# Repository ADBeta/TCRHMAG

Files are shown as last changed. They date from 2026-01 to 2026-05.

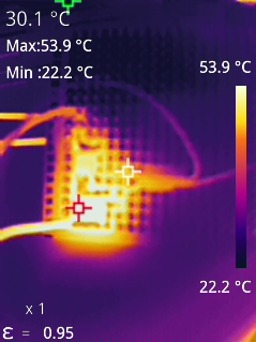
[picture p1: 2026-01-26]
Images/TestBoard_Thermals_100%PWM.jpg

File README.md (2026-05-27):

# Temperature Controlled Ryobi Hot Melt Adhesive Gun

An Upgrade Control Board for the R18GLU Hot Glue Gun to provide PID Temperature
Control, and display battery voltage, battery current.  
It also improves battery life to 1hr 45min on a 1.5Ah Ryobi Battery (At 150c).

## Features
This is a drop-in replacement Controller PCB, which provides:

* OLED Display which shows
    * Target and Actual Temperature
    * Battery Current draw
    * Battery Voltage (and Battery Bar)
* Overcurrent and Undervoltage Protection
* Adjustable PID Control loop
* LED Status Light
* Precise Temperature Control (+/-5 degrees celcius)

## How do I install this mod?
This upgrade will require ordering PCBs & components, soldering, modifying the
chassis, and barrel of the Glue Gun as well as 3D Printing.  
TCRHMAG is a medium difficulty hobby project.

1) Remove the Original Controller board and remove the wires from the Power Switch
2) **MODIFICATION STEPS**  
2a) Drill a small hole in the Glue Gun's heater barrel for better thermal control,
and use a thermally rated (280c) adhesive to attach an NTC Thermistor (TODO: images and specs of thermistor)
2b) Create a notch in both halves of the Glue Gun Shell for the OLED and Control wires (TODO: Images)
using a Dremel or sharp knife etc.
2c) (TODO: add display control 3d printed housing)
3) Install the programmed PCB
4) Solder the Power Switch to the PCB, and solder the Thermistor, Heater, LED
and Battery cables to the PCB
5) **3D PRINTED OLED HOUSING STEPS**
5a)......

## Programming The Microcontorller
**IMPORTANT** Solder and Flash the MCU **BEFORE** Assembling the rest of the PCB  
The NRST Line is used by an OpAmp circuit so it CANNOT be flashed in-situ until
the NRST line is disabled by the first Flash Cycle.
After this initial Programming Step, the board can be fully assembled and 
re-programmed if necessary without removing parts.

Use [minichlink](https://github.com/cnlohr/ch32fun/tree/master/minichlink) to
program the MCU.  
This project is built using [ch32fun](https://github.com/cnlohr/ch32fun).

## Bill of Materials

## To Do
* Display in Faranheit?
* Add better Rotary Encoder filter circuit
* Fix noisy battery voltage sensing
* Larget OLED / Rotary Encoder solder pads

----
Copyright (c) 2026 ADBeta

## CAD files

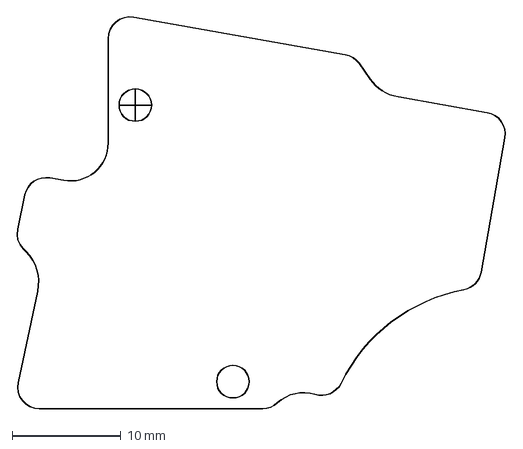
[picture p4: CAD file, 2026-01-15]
PCB/TCRHMAG-PCB-MkIII.dxf
45.2 x 36.2 mm

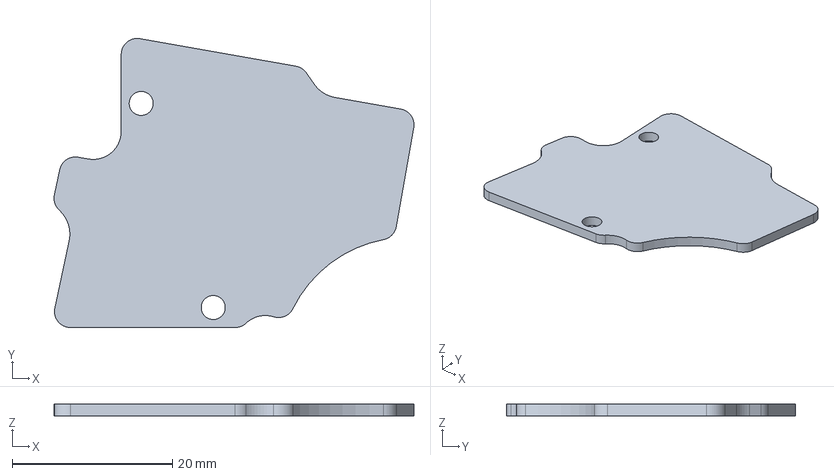
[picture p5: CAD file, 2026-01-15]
PCB/TCRHMAG.FCStd
45.0 x 36.1 x 1.50 mm

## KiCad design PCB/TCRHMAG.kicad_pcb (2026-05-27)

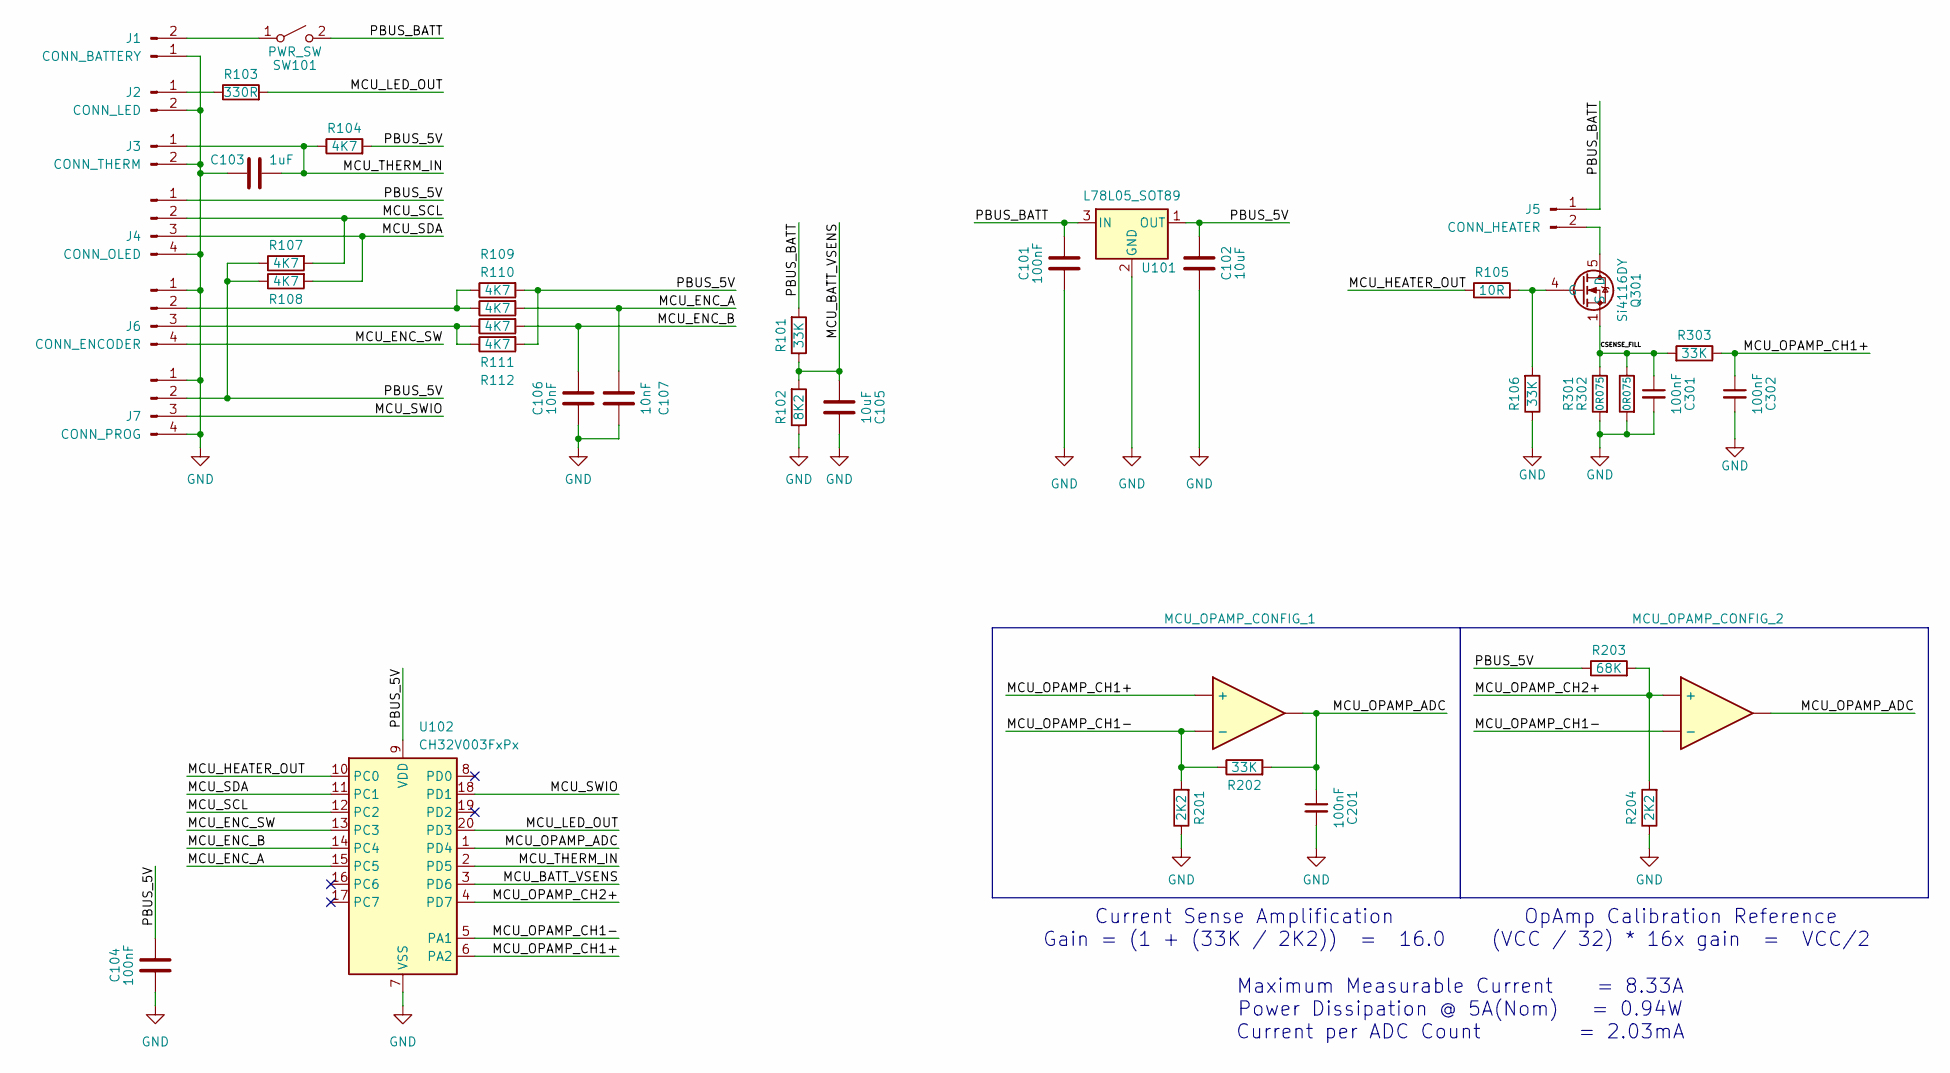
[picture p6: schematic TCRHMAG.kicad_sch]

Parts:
C101, C104, C201, C301, C302: 100nF; C_0402_1005Metric
C102, C105: 10uF; C_0402_1005Metric
C103: 1uF; C_0402_1005Metric
C106, C107: 10nF; C_0402_1005Metric
J1: CONN_BATTERY; Power_Conn
J2: CONN_LED; Signal_Conn
J3: CONN_THERM; Signal_Conn
J4: CONN_OLED; PinSocket_1x04_P2.00mm_Vertical
J5: CONN_HEATER; Power_Conn
J6: CONN_ENCODER; PinSocket_1x04_P2.00mm_Vertical
J7: CONN_PROG; Program_Conn
MCU_OPAMP_CONFIG_1, MCU_OPAMP_CONFIG_2: (no value)
Q301: Si4116DY; SOIC-8_3.9x4.9mm_P1.27mm
R101, R106, R202, R303: 33K; R_0402_1005Metric
R102: 8K2; R_0402_1005Metric
R103: 330R; R_0402_1005Metric
R104, R107, R108, R109, R110, R111, R112: 4K7; R_0402_1005Metric
R105: 10R; R_0402_1005Metric
R201, R204: 2K2; R_0402_1005Metric
R203: 68K; R_0402_1005Metric
R301, R302: 0R075; R_2512_6332Metric_Pad1.40x3.35mm_HandSolder
SW101: PWR_SW; U13SS_Switch
U101: L78L05_SOT89; SOT-89-3
U102: CH32V003FxPx; TSSOP-20_4.4x6.5mm_P0.65mm

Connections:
/CSENSE_FILL: C301.1, Q301.1 (S), Q301.2 (S), Q301.3 (S), R301.1, R302.1, R303.2
/MCU_BATT_VSENS: C105.1, R101.1, R102.2, U102.3 (PD6)
/MCU_ENC_A: C107.2, R110.2, U102.15 (PC5)
/MCU_ENC_B: C106.2, R111.2, U102.14 (PC4)
/MCU_ENC_SW: J6.4, U102.13 (PC3)
/MCU_HEATER_OUT: R105.1, U102.10 (PC0)
/MCU_LED_OUT: R103.2, U102.20 (PD3)
/MCU_OPAMP_ADC: C201.1, MCU_OPAMP_CONFIG_1.3, MCU_OPAMP_CONFIG_2.3, R202.2, U102.1 (PD4)
/MCU_OPAMP_CH1+: C302.1, MCU_OPAMP_CONFIG_1.1 (+), R303.1, U102.6 (PA2)
/MCU_OPAMP_CH1-: MCU_OPAMP_CONFIG_1.2 (-), MCU_OPAMP_CONFIG_2.2 (-), R201.2, R202.1, U102.5 (PA1)
/MCU_OPAMP_CH2+: MCU_OPAMP_CONFIG_2.1 (+), R203.2, R204.2, U102.4 (PD7)
/MCU_SCL: J4.2, R107.2, U102.12 (PC2)
/MCU_SDA: J4.3, R108.2, U102.11 (PC1)
/MCU_SWIO: J7.3, U102.18 (PD1)
/MCU_THERM_IN: C103.2, J3.1, R104.1, U102.2 (PD5)
/PBUS_5V: C102.1, C104.1, J4.1, J7.2, R104.2, R107.1, R108.1, R109.2, R112.2, R203.1, U101.1 (OUT), U102.9 (VDD)
/PBUS_BATT: C101.1, J5.1, R101.2, SW101.2 (B), U101.3 (IN)
GND: C101.2, C102.2, C103.1, C104.2, C105.2, C106.1, C107.1, C201.2, C301.2, C302.2, J1.1, J2.2, J3.2, J4.4, J6.1, J7.1, J7.4, R102.1, R106.1, R201.1, R204.1, R301.2, R302.2, U101.2 (GND), U102.7 (VSS)
unnamed: J1.2, SW101.1 (A)
unnamed: J2.1, R103.1
unnamed: J5.2, Q301.5 (D), Q301.6 (D), Q301.7 (D), Q301.8 (D)
unnamed: J6.2, R109.1, R110.1
unnamed: J6.3, R111.1, R112.1
unnamed: Q301.4 (G), R105.2, R106.2

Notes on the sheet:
OpAmp Calibration Reference (VCC / 32) * 16x gain = VCC/2
Current Sense Amplification Gain = (1 + (33K / 2K2)) = 16.0
Maximum Measurable Current = 8.33A Power Dissipation @ 5A(Nom) = 0.94W Current per ADC Count = 2.03mA

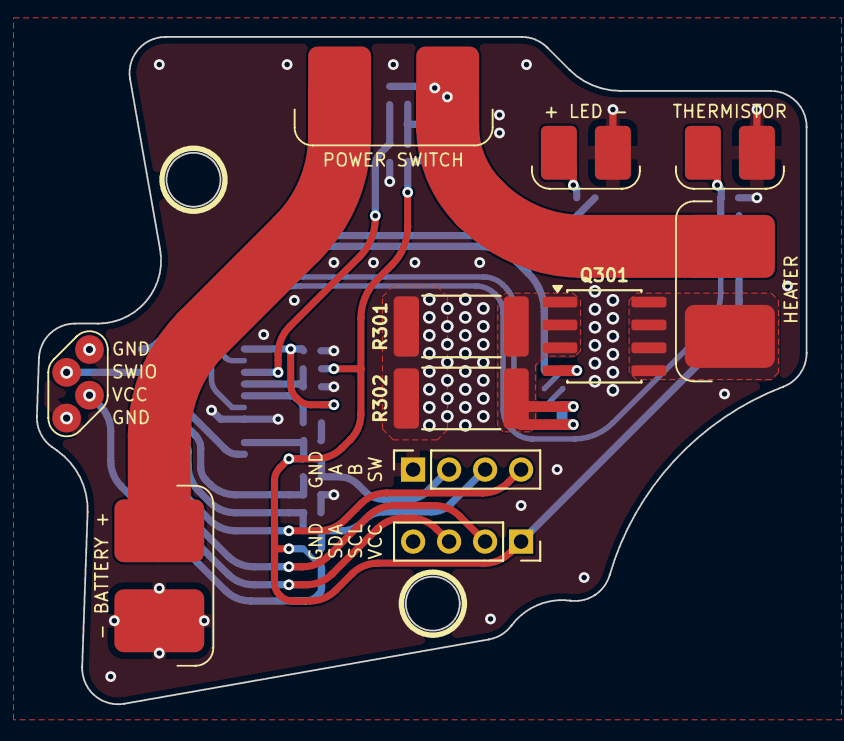
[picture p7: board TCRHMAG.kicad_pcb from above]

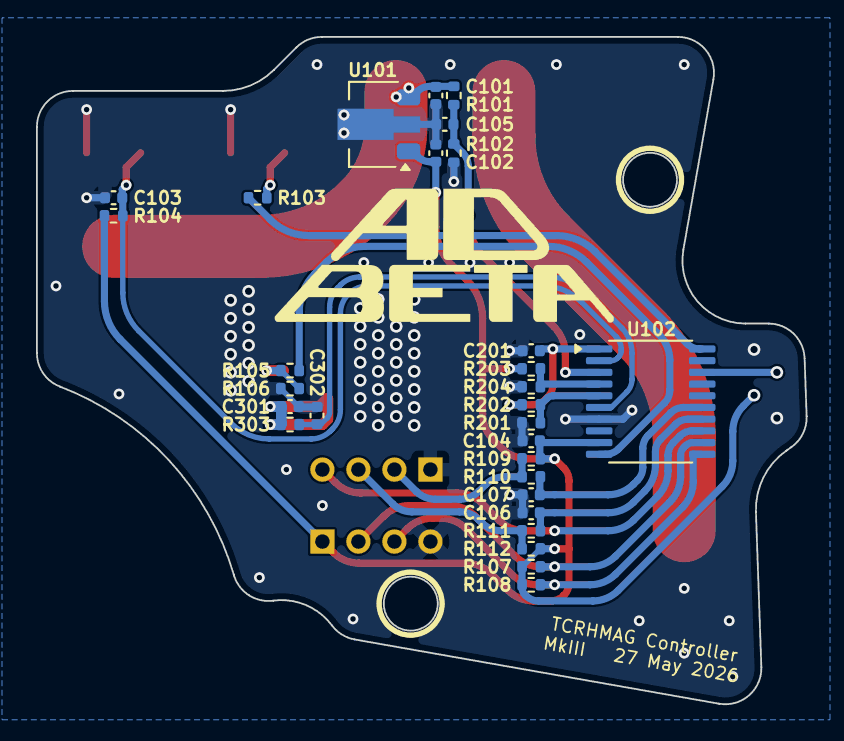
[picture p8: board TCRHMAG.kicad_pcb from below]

Board: 2 copper layers, 42.8 x 37.1 mm, 40 parts (29 on the bottom side), 24 nets.

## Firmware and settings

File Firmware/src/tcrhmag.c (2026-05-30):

/******************************************************************************
* PID Thermally Controlled Ryobi Hot Melt Adhesive Gun (HMAG)
* Uses OLED Display to show the Battery and Temperature Status, with
* Rotary Encoder for UI Inputs 
* See the GitHub for full documentation: https://github.com/ADBeta/TCRHMAG
*
*
* ---- Pinout ----
* PA1    OPAMP_CH1-
* PA2    OPAMP_CH1+
*
* PC0    PWM Out           (TIM2 CH3)
* PC1    I2C SDA
* PC2    I2C_SCL
* PC3    Rotary Encoder Switch
* PC4    Rotary Encoder A
* PC5    Rotary Encoder B
*
* PD3    LED Out           (TIM2 CH2)
* PD4    OPAMP_ADC         (ADC7)
* PD5    Thermistor ADC    (ADC5)
* PD6    Battery Sense     (ADC6)
* PD7    OPAMP_CH2+
*
* ---- TODO ----
* - Scheduler Library
* - Add UI for PID adjust
* - Store the previous Target temp in flash
*
* Ver 1.8     30 May 2026
* (c) ADBeta 2026
******************************************************************************/
#include <ch32fun.h>
#include "thermistor_lut.h"
#include "sysinit.h"
#include "battery.h"
#include "oled.h"

#include "lib_scheduler.h"
#include "lib_gpioctrl.h"
#include "lib_i2c.h"
#include "lib_pid.h"

#include <stdio.h>
#include <stdbool.h>



/*** Macro Functons **********************************************************/
#define CLAMP(x, min, max) ((x) < (min) ? (min) : ((x) > (max) ? (max) : (x)))



/*** Pin Definitions *********************************************************/
#define OPAMP_CHA1_NEG                GPIO_PA1
#define OPAMP_CHA1_POS                GPIO_PA2
#define OPAMP_CHA2_POS                GPIO_PD7
#define PWM_OUT                       GPIO_PC0

#define ROTENC_SW_PIN                 GPIO_PC3
#define ROTENC_A_PIN                  GPIO_PC4
#define ROTENC_B_PIN                  GPIO_PC5

#define THERM_ADC_PIN                 GPIO_A5
#define THERM_ADC_CH                  GPIO_ADC_A5
#define BSENS_ADC_PIN                 GPIO_A6
//#define BSENS_ADC_CH                GPIO_ADC_A6
#define OPAMP_ADC_PIN                 GPIO_A7
//#define OPAMP_ADC_CH                GPIO_ADC_A7

#define PWM_CHANNEL_LED               0
#define PWM_CHANNEL_HEATER            1



/*** Timing Values ***********************************************************/
#define MILLIS_LED_UPDATE            25
#define MILLIS_USER_INPUT_UPDATE     50
#define MILLIS_PID_HEATER_UPDATE     100
#define MILLIS_BATTERY_CHECK         250
#define MILLIS_DISPLAY_UPDATE        125



/*** Misc Definitions ********************************************************/
#define LED_OFF_PWM                  0
#define LED_MINIMUM_PWM              30
#define LED_MAXIMUM_PWM              255
#define LED_FLASH_TICKS              10


/*** Typedefs and Structures *************************************************/
typedef enum {
	SYSTEM_STATE_BOOT                      = 0,
	SYSTEM_STATE_HEATER_DISABLED,
	SYSTEM_STATE_HEATER_ENABLED,
	SYSTEM_STATE_ERROR_UNDERVOLTAGE,
	SYSTEM_STATE_ERROR_OVERCURRENT,
} system_state_e;

	
typedef enum {
	UI_MODE_UNSET                          = 0,
	UI_MODE_CHANGE_TEMP,
	UI_MODE_CHANGE_KP,
	UI_MODE_CHANGE_KI,
	UI_MODE_CHANGE_KD,
	UI_MODE_ERROR_UNDERVOLTAGE,
	UI_MODE_ERROR_OVERCURRENT,
} user_input_mode_e;



/*** Global Variables ********************************************************/
// External 1ms SysTick counter variable
volatile uint32_t _systick_millis                                = 0;


/// System Status and Settings ////////////////////////////////////////////////
// System //////
static system_state_e      g_system_state                        = SYSTEM_STATE_BOOT;
static user_input_mode_e   g_user_input_mode                     = UI_MODE_CHANGE_TEMP;
static volatile int16_t    g_rotary_encoder_clicks               = 0;
// Battery /////
static uint16_t            g_battery_voltage_mv                  = 0;
static uint16_t            g_battery_current_ma                  = 0;
static uint8_t             g_battery_percentage                  = 0;
// Heater //////
#define                    SETTING_TEMPERATURE_MINIMUM           50
#define                    SETTING_TEMPERATURE_MAXIMUM           220
#define                    SETTING_TEMPERATURE_INCRIMENT         5
static int16_t             g_target_temperature                  = SETTING_TEMPERATURE_MINIMUM;
static int16_t             g_actual_temperature                  = 0;

/// @brief Gray Code Lookup Table for the Rotary Encoder
static const int8_t rotenc_table[16] = 
{
	 0,  -1,   1,   0,
	 1,   0,   0,  -1,
	-1,   0,   0,   1,
	 0,   1,  -1,   0
};

/// @brief Base Settings for the PID Controller for the Heater
static pid_ctrl_t heater_pid =
{
	.Kp        = 1000,
	.Ki        = 5,
	.Kd        = 5,
	.scale     = 100,

	.out_min   = 0,
	.out_max   = 255
};

/// @brief I2C Device for the OLED
static i2c_device_t i2c_oled = 
{
	.clkr = I2C_CLK_1MHZ,
	.type = I2C_ADDR_7BIT,
	.addr = 0x3C,
	.regb = 1,
	.tout = 2000,
};



/*** Scheduler Task Functions ************************************************/
/// @brief Updates the Status LED
static void led_update_task(void);

/// @brief Gets User Input Values
static void user_input_task(void);

/// @biref Update PID Controller for the heater
static void pid_heater_task(void);

/// @brief Check the battery Voltage/Current
static void battery_check_task(void);

/// @brief Update the display
static void display_update_task(void);



/*** Function Declarations ***************************************************/
/// @brief Initialises the EXTI7_0 Rotary Encoder IRQ
/// @param None
/// @return None
static void EXTI7_0_Init(void);


/// @brief EXTI Pin Change Interrupt - Handles the Rotary Encoder stepping
/// @param None
/// @return None
__attribute__((interrupt)) 
void EXTI7_0_IRQHandler(void);


/// @breif Sets the Duty Cycle of the given PWM Channel. Max input is 255
/// @param ch, channel to change (Only 2 & 3 are valid)
/// @param duty, input duty cycle value
/// @return none
static void pwm_set_duty(const uint8_t ch, const uint32_t duty);


/// @brief Converts a given Thermistor Raw ADC Value to a Temperature (c)
/// using Linear Interpolation of the Pre-computed LUT
/// @param adc, Raw ADC Value of the Thermistor
/// @return Temperature in degrees Celcius
static uint16_t thermistor_adc_to_temp(const uint16_t adc);



/*** Main ********************************************************************/
int main(void)
{
	SystemInit();

	// I2C Setup for the OLED
	i2c_init(&i2c_oled);

	// Initialise the OLED, then display the BOOTING Screen
	Delay_Ms(20);
	oled_init(&i2c_oled);
	oled_draw_boot_screen();
	oled_update();

	// Initialise PWM Channels. Turn off the Heater (CH3) and the LED on (CH2)
	pwm_init();
	pwm_set_duty(PWM_CHANNEL_LED,    0x00);
	pwm_set_duty(PWM_CHANNEL_HEATER, 0x00);
	
	// Set the Rotary Encoder Pins to INPUT_PULLUP
	gpio_set_mode(ROTENC_SW_PIN, INPUT_PULLUP);
	gpio_set_mode(ROTENC_A_PIN,  INPUT_PULLUP);
	gpio_set_mode(ROTENC_B_PIN,  INPUT_PULLUP);

	// Initiliase the ADC to use 24MHz clock, and Sample for 43 Clock Cycles
	gpio_init_adc(ADC_CLOCK_DIV_2, ADC_SAMPLE_CYCLES_43);

	// Initialise the OpAmp Pins - Use CHA1 +/-,  CHA2 +, and ADC Output
	gpio_set_mode(OPAMP_CHA1_NEG, INPUT_FLOATING);
	gpio_set_mode(OPAMP_CHA1_POS, INPUT_FLOATING);
	gpio_set_mode(OPAMP_CHA2_POS, INPUT_FLOATING);

	gpio_set_mode(THERM_ADC_PIN,  INPUT_ANALOG);
	gpio_set_mode(BSENS_ADC_PIN,  INPUT_ANALOG);
	gpio_set_mode(OPAMP_ADC_PIN,  INPUT_ANALOG);	

	gpio_init_opamp();
	gpio_set_opamp_inputs(GPIO_OPAMP_CH1_POS, GPIO_OPAMP_CH1_NEG);
	opamp_calibrate();

	// Initialise the Rotary Encoder IRQ
	EXTI7_0_Init();

	// Initialise the SysTick to get millis() funcitonality
	systick_init();

	// TODO:
	// Get user settings from flash
	pid_init(&heater_pid);

	// TODO: Change via UI
	g_system_state    = SYSTEM_STATE_HEATER_DISABLED;
	g_user_input_mode = UI_MODE_CHANGE_TEMP;
	

	// Add all the tasks to the scheduler
	scheduler_add(led_update_task,     MILLIS_LED_UPDATE);
	scheduler_add(user_input_task,     MILLIS_USER_INPUT_UPDATE);
	scheduler_add(pid_heater_task,     MILLIS_PID_HEATER_UPDATE);
	scheduler_add(battery_check_task,  MILLIS_BATTERY_CHECK);
	scheduler_add(display_update_task, MILLIS_DISPLAY_UPDATE);


	// Initialise the IWDT to prevent a lockup - 250ms
	iwdg_init(0x04, 0x9B);


	while(true)
	{
		// Run the Scheduler
		scheduler_run(_systick_millis);

		// Keep the Watchdog fed and happy :)
		iwdg_feed();
	}

	return 0;
}







/*** Scheduler Functions *****************************************************/
static void led_update_task(void)
{
	static int16_t led_val   = 0;
	static int8_t  led_inc   = 5;
	static uint8_t led_ticks = LED_FLASH_TICKS;
	
	switch(g_system_state)
	{
		case SYSTEM_STATE_HEATER_DISABLED:
			led_val = LED_MINIMUM_PWM;
			break;
	
		case SYSTEM_STATE_HEATER_ENABLED:
			led_val += led_inc;
			if(led_val >= LED_MAXIMUM_PWM || led_val <= LED_MINIMUM_PWM)
			{
				led_val = (led_val >= LED_MAXIMUM_PWM) ? LED_MAXIMUM_PWM : LED_MINIMUM_PWM;
				led_inc = -led_inc;
			}
			break;

		case SYSTEM_STATE_ERROR_OVERCURRENT:
		case SYSTEM_STATE_ERROR_UNDERVOLTAGE:
			if(--led_ticks == 0)
			{
				led_val = (led_val == LED_OFF_PWM) ? LED_MAXIMUM_PWM : LED_OFF_PWM;
				led_ticks = LED_FLASH_TICKS;
			}
			break;

		default:
			led_val = LED_OFF_PWM;
			break;
	}

	// Set the LED PWM
	pwm_set_duty(PWM_CHANNEL_LED, (uint8_t)led_val);
}


static void user_input_task(void)
{
	// Determine if the RENC button has been pressed
           GPIO_STATE curr = gpio_digital_read(ROTENC_SW_PIN);
	static GPIO_STATE prev = true;
	bool button_pressed = (prev && !curr);
	prev = curr;


	// If the system in is the error state, ignore all user inputs
	if(g_system_state == SYSTEM_STATE_ERROR_UNDERVOLTAGE || g_system_state == SYSTEM_STATE_ERROR_OVERCURRENT)
	{
		g_rotary_encoder_clicks = 0;
		return;
	}

	//TODO: Move UI stuff to helper function and .h for neatness
	switch(g_user_input_mode)
	{
		case UI_MODE_CHANGE_TEMP:
			// Incriment / Decriment the Target Temp by the current clicks
			// Limit to min and max values, then reset clicks
			g_target_temperature = CLAMP(g_target_temperature + g_rotary_encoder_clicks * SETTING_TEMPERATURE_INCRIMENT, 
								         SETTING_TEMPERATURE_MINIMUM, 
								         SETTING_TEMPERATURE_MAXIMUM);
			
			// Toggle ENABLE if button was pressed
			if(button_pressed)
			{
				// TODO: Neater
				if(g_system_state == SYSTEM_STATE_HEATER_DISABLED)
				{
					g_system_state = SYSTEM_STATE_HEATER_ENABLED;
				} else if(g_system_state == SYSTEM_STATE_HEATER_ENABLED) {
					g_system_state = SYSTEM_STATE_HEATER_DISABLED;
				}
			}
			break;

		default:
			break;
	}
	

	g_rotary_encoder_clicks = 0;
}


static void pid_heater_task(void)
{
	// Get the RAW ADC Value from the Thermistor, and convert it to an
	// interpolated Temperature
	uint16_t thermistor_adc = gpio_analog_read(THERM_ADC_CH);
	g_actual_temperature = thermistor_adc_to_temp(thermistor_adc);
	
	// Calculate the PWM Value needed for the heater using PID - regardless
	// of enabled state to keep the PID loop up-to-date
	int32_t heater_pwm = pid_calculate(&heater_pid, g_actual_temperature, g_target_temperature);
	
	// If the heater is disabled, set PWM value to 0 (OFF)
	if(g_system_state != SYSTEM_STATE_HEATER_ENABLED) 
		heater_pwm = 0x00;
	
	pwm_set_duty(PWM_CHANNEL_HEATER, (uint8_t)heater_pwm);
}


static void battery_check_task(void)
{
	uint16_t system_mv = gpio_read_system_mv();

	g_battery_voltage_mv = battery_read_mv(system_mv);
	g_battery_percentage = battery_calc_battery_percent(g_battery_voltage_mv);
	g_battery_current_ma = battery_read_average_ma(system_mv);

	// If the battery voltage drops below the minimum, or the current
	// goes above maximum, put the glue gun into a lockout state to
	// failsafe. Also starts to cooldown
	static uint8_t error_ticks = 10;
	bool voltage_fault = (g_battery_voltage_mv <= BATTERY_EMPTY_MV); 
	bool current_fault = (g_battery_current_ma >= BATTERY_OVERCURRENT_MA);
	
	if(!voltage_fault && !current_fault)
		error_ticks = 10;

	if(--error_ticks == 0)
	{
		g_system_state = voltage_fault ? SYSTEM_STATE_ERROR_UNDERVOLTAGE :
		                                 SYSTEM_STATE_ERROR_OVERCURRENT;
		
		g_user_input_mode = voltage_fault ? UI_MODE_ERROR_UNDERVOLTAGE :
			                                UI_MODE_ERROR_OVERCURRENT;
	}
}


static void display_update_task(void)
{
	static user_input_mode_e p_user_input_mode = UI_MODE_UNSET;
	if(p_user_input_mode != g_user_input_mode)
	{
		oled_clear_display();
		p_user_input_mode = g_user_input_mode;
	}

	switch(g_user_input_mode)
	{
		case UI_MODE_CHANGE_TEMP:
			oled_draw_battery_current(g_battery_current_ma);
//			oled_draw_battery_voltage(g_battery_voltage_mv);
			oled_draw_battery_percent(g_battery_percentage);
			oled_draw_temperature(g_target_temperature, g_actual_temperature);
			oled_draw_heater_state(g_system_state == SYSTEM_STATE_HEATER_ENABLED);
			break;

		case UI_MODE_ERROR_UNDERVOLTAGE:
			oled_draw_error_undervoltage_screen();
			break;

		case UI_MODE_ERROR_OVERCURRENT:
			oled_draw_error_overcurrent_screen();
			break;

		default:
			break;
	}

	oled_update();
}



/*** Function Definitions ****************************************************/
static void EXTI7_0_Init(void)
{
	// Enable AFIO and CH4 and CH5 on PORTC
	RCC->APB2PCENR |= RCC_APB2Periph_AFIO;
	AFIO->EXTICR    = AFIO_EXTICR_EXTI4_PC | AFIO_EXTICR_EXTI5_PC;
	
	// Enable IRQ on Channel 4 & 5, Rising or Falling Edge
	EXTI->INTENR    = EXTI_INTENR_MR4 | EXTI_INTENR_MR5;
	EXTI->RTENR     = EXTI_RTENR_TR4  | EXTI_RTENR_TR5;
	EXTI->FTENR     = EXTI_FTENR_TR4  | EXTI_FTENR_TR5;

	// Clear IRQ Flags before enabling for safety
	EXTI->INTFR = 0x00000030;
	// Enable the EXTI0-7 Interrupt Group in NVIC
	NVIC_EnableIRQ(EXTI7_0_IRQn);
}


__attribute__((interrupt))
void EXTI7_0_IRQHandler(void)
{
	// Trigger on CH4 and CH5
	if((EXTI->INTFR & 0x00000010) || (EXTI->INTFR & 0x00000020))
	{
		// Read the PORT Input Register to get the Pinm Bits
		uint32_t portc_read = GPIOC->INDR;

		// Clear whichever flag was hit
		if(EXTI->INTFR & 0x10) EXTI->INTFR = 0x10;
		if(EXTI->INTFR & 0x20) EXTI->INTFR = 0x20;

		// Accumulate transitions per detend (usually 4) 
		static int8_t accumulator     = 0;
		
		// Read A and B Pins (PC4 & PC5), use their state as bits in a bitmask. [AB]
		static int8_t rotenc_prev_bitmask = 0b11;
		       int8_t rotenc_curr_bitmask = (((portc_read >> 4) & 1) << 1) | ((portc_read >> 5) & 1);

		// Convert the bitmasks into a step value using the Gray Code Table
		int8_t step = rotenc_table[ (rotenc_prev_bitmask << 2) | rotenc_curr_bitmask ];
		accumulator += step;

		// If the Accumulator has incrimented or decrimented by the number of clicks
		// per indent (4), incriment or decriment the global value
		     if(accumulator >=  4) { g_rotary_encoder_clicks++; accumulator -= 4; }
		else if(accumulator <= -4) { g_rotary_encoder_clicks--; accumulator += 4; }
	
		// Update the prev bitmask for the next interrupt
		rotenc_prev_bitmask = rotenc_curr_bitmask;
	}
}


static  void pwm_set_duty(const uint8_t ch, const uint32_t duty)
{
	static volatile uint32_t *tim_ptr[2] = { &TIM2->CH2CVR, &TIM2->CH3CVR };
	*tim_ptr[ch] = duty;
}


static uint16_t thermistor_adc_to_temp(const uint16_t adc)
{
	const size_t therm_max_index = THERMISTOR_PAIR_ENTRIES - 1;
	
	// Cap the Upper and Lower Bounds
	if(adc >= thermistor_pair[0].adc)
		return thermistor_pair[0].temp_c;
	
	if(adc <= thermistor_pair[therm_max_index].adc)
		return thermistor_pair[therm_max_index].temp_c;


	// Find the LUT ADC Range
	for(size_t ti = 0; ti < therm_max_index; ti++)
	{
		// Get the Current and Next ADC Values in the pair table.
		uint16_t adc0  = thermistor_pair[ti].adc;
		uint16_t adc1  = thermistor_pair[ti + 1].adc;

		// ADC Values Decrease as temperature rises. Check if adc input is within
		// the current check range
		if(adc <= adc0 && adc >= adc1)
		{
			// Get Current and Next Temp values in the pair table
			uint16_t temp0 = thermistor_pair[ti].temp_c;
			uint16_t temp1 = thermistor_pair[ti + 1].temp_c;

			// Linear Interpolation. ADC Decreases with Temperature Rise:
			uint32_t delta_adc   = adc0 - adc;
			uint32_t span_adc    = adc0 - adc1;
			uint32_t delta_temp  = temp1 - temp0;

			return temp0 + (delta_adc * delta_temp) / span_adc;
		}
	}

	// LUT Ordering error: Should never be this
	return 0;
}

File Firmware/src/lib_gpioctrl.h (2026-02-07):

/******************************************************************************
* lib_gpioctrl
* A runtime-capable GPIO Library, with Digital Read/Write and Analog Read
*
* See GitHub for details: https://github.com/ADBeta/CH32V003_lib_gpioctrl
*
* ADBeta (c)    26 Jan 2026    Ver 1.4.0
******************************************************************************/
#ifndef LIB_GPIOCTRL_H
#define LIB_GPIOCTRL_H

#include <stdint.h>
#include <stddef.h>

#define GPIO_ADC_MAXIMUM           1023   // Maximum ADC Value
#define GPIO_ADC_REF_MV            1200   // Internal VREF Voltage (mV)



/*** GPIO Pin Enumeration ****************************************************/
/// @breif This enum is used as binary data for pin and port addressing. 
/// 0x[PIN][PORT] - 0x 0603 6th pin of port 4 (PORTD)
/// NOTE: Little-Endian Architecture means value in memory is [PORT][PIN] order
typedef enum {
	GPIO_PA0	  = 0x0000,
	GPIO_PA1	  = 0x0100, 
	GPIO_PA2	  = 0x0200, 
	GPIO_PA3	  = 0x0300,
	GPIO_PA4	  = 0x0400,
	GPIO_PA5	  = 0x0500,
	GPIO_PA6	  = 0x0600,
	GPIO_PA7	  = 0x0700,

	GPIO_PB0	  = 0x0001,
	GPIO_PB1	  = 0x0101, 
	GPIO_PB2	  = 0x0201, 
	GPIO_PB3	  = 0x0301,
	GPIO_PB4	  = 0x0401,
	GPIO_PB5	  = 0x0501,
	GPIO_PB6	  = 0x0601,
	GPIO_PB7	  = 0x0701,

	GPIO_PC0	  = 0x0002,
	GPIO_PC1	  = 0x0102, 
	GPIO_PC2	  = 0x0202, 
	GPIO_PC3	  = 0x0302,
	GPIO_PC4	  = 0x0402,
	GPIO_PC5	  = 0x0502,
	GPIO_PC6	  = 0x0602,
	GPIO_PC7	  = 0x0702,

	GPIO_PD0	  = 0x0003,
	GPIO_PD1	  = 0x0103, 
	GPIO_PD2	  = 0x0203, 
	GPIO_PD3	  = 0x0303,
	GPIO_PD4	  = 0x0403,
	GPIO_PD5	  = 0x0503,
	GPIO_PD6	  = 0x0603,
	GPIO_PD7	  = 0x0703,

	// Map Analog Pins
	// If the CPU Is a CH32V003
	#ifdef CH32V003
	GPIO_A0	   = 0x0200,	 // PA2
	GPIO_A1	   = 0x0100,	 // PA1
	GPIO_A2	   = 0x0402,	 // PC4
	GPIO_A3	   = 0x0203,	 // PD2
	GPIO_A4	   = 0x0303,	 // PD3
	GPIO_A5	   = 0x0503,	 // PD5
	GPIO_A6	   = 0x0603,	 // PD6
	GPIO_A7	   = 0x0403,	 // PD4
	#endif
} GPIO_PIN;


/// @breif analog input pins, sorted by channel
typedef enum {
	GPIO_ADC_A0	     = 0x00,
	GPIO_ADC_A1	     = 0x01,
	GPIO_ADC_A2	     = 0x02,
	GPIO_ADC_A3	     = 0x03,
	GPIO_ADC_A4	     = 0x04,
	GPIO_ADC_A5	     = 0x05,
	GPIO_ADC_A6	     = 0x06,
	GPIO_ADC_A7	     = 0x07,
	GPIO_ADC_VREF	 = 0x08,
	GPIO_ADC_VCAL	 = 0x09,
} GPIO_ANALOG_CHANNEL;



/*** GPIO Pin Mode Enumeration ***********************************************/
/// @breif GPIO Pin Mode data. The lower nibble is the raw binary data for the
/// [R32_GPIOx_CFGLR] Register. The upper nibble is used for additional flags 
typedef enum {
	INPUT_ANALOG	   = 0x00,
	INPUT_FLOATING	   = 0x04,
	// Mapped to INPUT_PP, Sets OUTDR based on the upper nibble
	INPUT_PULLUP	   = 0x18,
	INPUT_PULLDOWN	   = 0x08,
	//
	OUTPUT_10MHZ_PP	   = 0x01,
	OUTPUT_10MHZ_OD	   = 0x05,
	//
	OUTPUT_2MHZ_PP	   = 0x02,
	OUTPUT_2MHZ_OD	   = 0x06,
	//
	OUTPUT_PP_AF	   = 0x08,
	OUTPUT_OD_AF	   = 0x0C,
} GPIO_MODE;



/*** ADC Setting Enumeration *************************************************/
/// @breif a sample of ADC clock division settings (Bits 15:11 in RCC->CFGR0)
typedef enum {
	ADC_CLOCK_DIV_2   = (uint32_t)0x00000000,
	ADC_CLOCK_DIV_32  = (uint32_t)0x00003800,
	ADC_CLOCK_DIV_64  = (uint32_t)0x00007800,
	ADC_CLOCK_DIV_128 = (uint32_t)0x0000F800,
} ADC_CLOCK_DIV;


/// @brief ADC Sample Settings. Pre-calculated Sample Bits for all channels
typedef enum {
	ADC_SAMPLE_CYCLES_3    = (uint32_t)0x00000000,
	ADC_SAMPLE_CYCLES_9    = (uint32_t)0x09249249,
	ADC_SAMPLE_CYCLES_15   = (uint32_t)0x12492492,
	ADC_SAMPLE_CYCLES_30   = (uint32_t)0x1B6DB6DB,
	ADC_SAMPLE_CYCLES_43   = (uint32_t)0x24924924,
	ADC_SAMPLE_CYCLES_57   = (uint32_t)0x2DB6DB6D,
	ADC_SAMPLE_CYCLES_73   = (uint32_t)0x36DB6DB6,
	ADC_SAMPLE_CYCLES_241  = (uint32_t)0x3FFFFFFF,
} ADC_SAMPLE_CYCLES;



/*** GPIO Output State Enumerations ******************************************/
/// @breif GPIO Pin State Enum, simple implimentation of a HIGH/LOW System
typedef enum {
	GPIO_LOW	       = 0x00,
	GPIO_HIGH	       = 0x01,
} GPIO_STATE;



/*** Registers for GPIO Port *************************************************/
/// @breif GPIO Port Register, Directly Maps to Memory starting at 
/// [R32_GPIOx_CFGLR] for each PORT Respectively
typedef struct {
	volatile uint32_t CFGLR;  // Configuration Register (lower)
	volatile uint32_t CFGHR;  // Configuration Register (upper)
	volatile uint32_t INDR;   // Input Data Register
	volatile uint32_t OUTDR;  // Output Data Register
	volatile uint32_t BSHR;   // Set/Reset Register
	volatile uint32_t BCR;	  // Port Reset Register
	volatile uint32_t LCKR;   // Lock Register
} GPIO_PORT_REG_TypeDef;
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

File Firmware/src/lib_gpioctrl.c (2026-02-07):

/******************************************************************************
* lib_gpioctrl
* A runtime-capable GPIO Library, with Digital Read/Write and Analog Read
*
* See GitHub for details: https://github.com/ADBeta/CH32V003_lib_gpioctrl
*
* ADBeta (c) 2024-2026
******************************************************************************/
#include "lib_gpioctrl.h"
#include <stdint.h>


GPIO_PORT_REG_TypeDef *GPIO_PORT_MAP[4] = {
	GPIO_PORTA,
	NULL,
	GPIO_PORTC,
	GPIO_PORTD,
};


void gpio_set_mode(const GPIO_PIN pin, const GPIO_MODE mode)
{
	// TODO: Any pin over 8 needs to change CFGHR
	
	// Make array of uint8_t from [pin] enum. See definition for details
	uint8_t *byte = (uint8_t *)&pin;
	
	// Set the RCC Register to enable clock on the specified port
	GPIO_RCC->APB2PCENR |= (RCC_APB2PCENR_AFIO | (RCC_APB2PCENR_IOPxEN << byte[0]));

	// Clear then set the GPIO Config Register
	GPIO_PORT_MAP[ byte[0] ]->CFGLR &=        ~(0x0F  << (4 * byte[1]));
	GPIO_PORT_MAP[ byte[0] ]->CFGLR |=  (mode & 0x0F) << (4 * byte[1]);

	// If [mode] is INPUT_PULLUP or INPUT_PULLDOWN, set the [OUTDR] Register
	if(mode == INPUT_PULLUP || mode == INPUT_PULLDOWN)
		gpio_digital_write(pin, mode >> 4);
}


void gpio_init_opamp(void)
{
	GPIO_EXTEN->EXTEN_CTR |= GPIO_EXTEN_OPA_EN;
}


void gpio_set_opamp_inputs(const GPIO_OPAMP_CH_POS pos, 
						   const GPIO_OPAMP_CH_NEG neg)
{
	// Positive Input
	GPIO_EXTEN->EXTEN_CTR =
		(GPIO_EXTEN->EXTEN_CTR & ~GPIO_EXTEN_OPA_PSEL) |
		((pos == GPIO_OPAMP_CH2_POS) ? GPIO_EXTEN_OPA_PSEL : 0);

	// Negative Input
	GPIO_EXTEN->EXTEN_CTR =
		(GPIO_EXTEN->EXTEN_CTR & ~GPIO_EXTEN_OPA_NSEL) |
		((neg == GPIO_OPAMP_CH2_NEG) ? GPIO_EXTEN_OPA_NSEL : 0);
}


__attribute__((always_inline))
inline void gpio_digital_write(const GPIO_PIN pin, const GPIO_STATE state)
{
	// Make array of uint8_t from [pin] enum. See definition for details
	uint8_t *byte = (uint8_t *)&pin;

	uint32_t mask = 0x01 << byte[1];          // Shift by pin number
	if(state == GPIO_LOW) mask = mask << 16;  // Shift by 16 if LOW, to Reset

	GPIO_PORT_MAP[ byte[0] ]->BSHR = mask;
}


__attribute__((always_inline))
inline GPIO_STATE gpio_digital_read(const GPIO_PIN pin)
{
	// Make array of uint8_t from [pin] enum. See definition for details
	uint8_t *byte = (uint8_t *)&pin;

	// If the Input Reg has the wanted bit set, return HIGH
	if( (GPIO_PORT_MAP[ byte[0] ]->INDR & (0x01 << byte[1])) != 0x00 ) 
		return GPIO_HIGH;

	// else return LOW 
	return GPIO_LOW;
}


void gpio_init_adc(const ADC_CLOCK_DIV div, const ADC_SAMPLE_CYCLES cycles)
{
	// Enable the ADC clock
	GPIO_RCC->APB2PCENR |= RCC_APB2Periph_ADC1;

	// Set ACD Clock Divider
	GPIO_RCC->CFGR0 &= ~ADC_CLOCK_DIV_128;
	GPIO_RCC->CFGR0 |= div;

	// Reset the ADC, Inits all registers
	GPIO_RCC->APB2PRSTR |=  RCC_APB2Periph_ADC1;
	GPIO_RCC->APB2PRSTR &= ~RCC_APB2Periph_ADC1;
	
	// Set rule channel conversion to all 0, ready for read
	GPIO_ADC1->RSQR1 = 0;
	GPIO_ADC1->RSQR2 = 0;
	GPIO_ADC1->RSQR3 = 0;

	// Set the Sample Register(s) for all channels at once
	GPIO_ADC1->SAMPTR1 = cycles;
	GPIO_ADC1->SAMPTR2 = cycles;

	// Enable the ADC, and set the triggering to external
	GPIO_ADC1->CTLR2 |= ADC_ADON | ADC_EXTSEL;
	
	// Reset calibration, wait for it to finish
	GPIO_ADC1->CTLR2 |= ADC_RSTCAL;
	while(GPIO_ADC1->CTLR2 & ADC_RSTCAL);

	// Calibrate the ADC, want for it to finish
	GPIO_ADC1->CTLR2 |= ADC_CAL;
	while(GPIO_ADC1->CTLR2 & ADC_CAL);
}


__attribute__((always_inline))
inline uint16_t gpio_analog_read(const GPIO_ANALOG_CHANNEL chan)
{
	// Set rule channel conversion for single conversion on passed channel
	// GPIO_ADC1->RSQR1 = 0;
	// GPIO_ADC1->RSQR2 = 0;
	GPIO_ADC1->RSQR3 = (uint32_t)chan;

	GPIO_ADC1->CTLR2 |= ADC_SWSTART;
	while(!(GPIO_ADC1->STATR & ADC_EOC));

	// Get the resulting data from the ADC
	return GPIO_ADC1->RDATAR;
}


uint16_t gpio_read_system_mv(void)
{
	// Get the raw ADC Value for the VREF - shift by 10 (*1024),
	// then divide it by the ADC maximum.
	// This is the VREF Multiplier
	uint32_t vref_multiplier = ((uint32_t)GPIO_ADC_MAXIMUM << 10) / gpio_analog_read(GPIO_ADC_VREF);

	// The mV value is equal to the ADC_VREF Millivolts, multiplied by the VREF
	// Multiplier, then shifted by 10 (/1024) to scale back down to mV
	return (GPIO_ADC_REF_MV * vref_multiplier) >> 10;
}

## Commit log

2026-01-15 PCB Started
    [TCRHMAG-PCB-MkIII.dxf, TCRHMAG.FCStd, TCRHMAG.kicad_pcb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]
2026-01-17 PCB Components Chosen
    [TCRHMAG.kicad_pcb, TCRHMAG.kicad_sch]
2026-01-20 Board Shape and Pad Placements
    [TCRHMAG.kicad_pcb]
2026-01-23 Thermistor updates
2026-01-24 Added Current Sense to circuit
    [TCRHMAG.kicad_pcb, TCRHMAG.kicad_sch]
2026-01-26 Added High Current and MCU to PCB
    [TCRHMAG.kicad_pcb, TCRHMAG.kicad_sch]
2026-02-10 Firmware Testing
    [TCRHMAG.kicad_pcb, TCRHMAG.kicad_sch]
2026-03-06 Added temperature Linear Interpolation
    [TCRHMAG.kicad_pcb, TCRHMAG.kicad_sch]
2026-03-07 PID Control loop testing
2026-03-09 PID Heater control tested and tuned
    [TCRHMAG.kicad_sch]
2026-03-10 Final PCB
    [TCRHMAG.kicad_pcb, TCRHMAG.kicad_sch]
2026-03-12 Rotary Encoder and OpAmp Current Reading improvements
2026-03-14 Rotary Encoder to IRQ
2026-03-19 Fixed SWIO Bug. MkII HW
    [TCRHMAG.kicad_pcb, TCRHMAG.kicad_sch]
2026-03-19 I2C And OLED Testing
2026-05-04 OLED Framebuffer testing
2026-05-06 Revising oled handler functions for battery status
2026-05-08 Refactored OLED draw routines and added battery percent icons
2026-05-18 V1.1 added Bootscreen and fixed bug
    [oled.c, tcrhmag.c]
2026-05-19 V1.3 Added heater indictor and Error state LED flashing
    [oled.c, tcrhmag.c]
2026-05-20 V1.4 Improve failsafe mode
    [battery.h, tcrhmag.c]
2026-05-25 MkIII PCB Finished
    [TCRHMAG.kicad_pcb, TCRHMAG.kicad_sch]
2026-05-27 PCB MkIII Final version gerber output. Changed gitignore
    [TCRHMAG.kicad_pcb]
